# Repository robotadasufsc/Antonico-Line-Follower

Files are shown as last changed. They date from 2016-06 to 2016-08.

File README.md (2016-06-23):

# Antonico-Line-Follower 
A line follower robot designed and built mostly by the new members of the Robota mobile robotics groups.

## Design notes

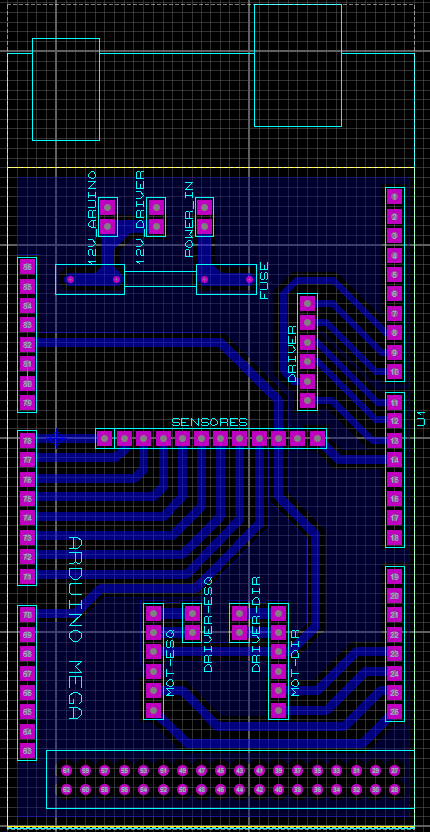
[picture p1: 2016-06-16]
Eletronica/ares.PNG

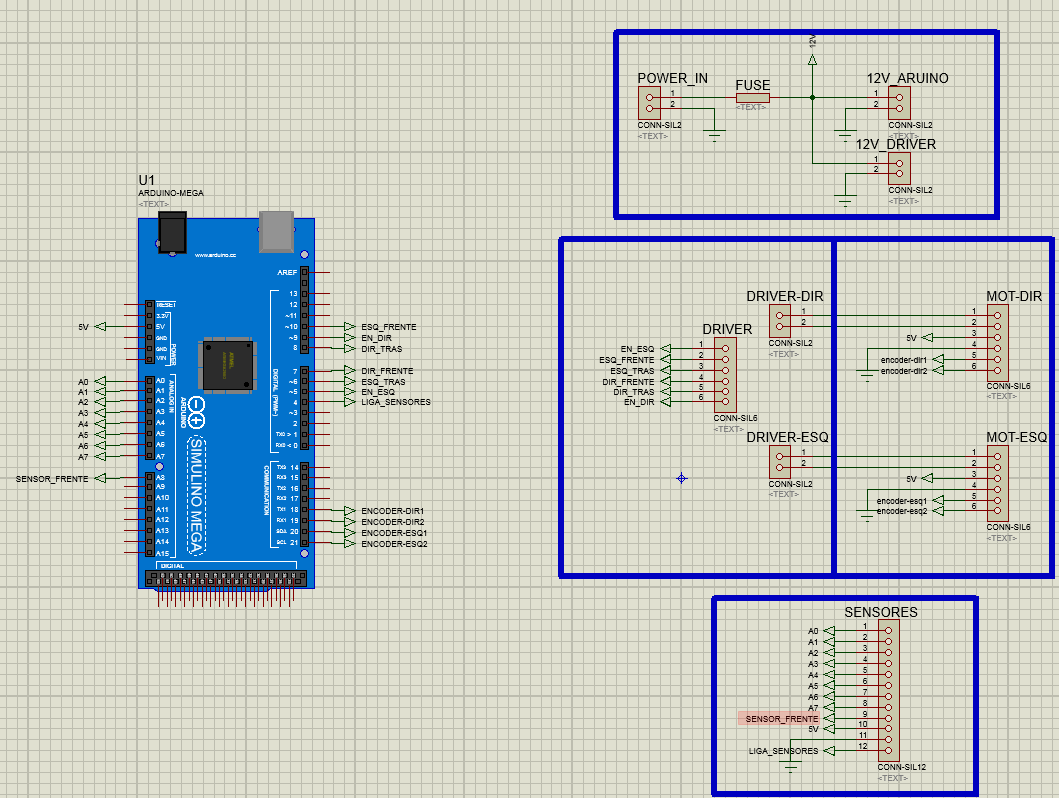
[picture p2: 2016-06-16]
Eletronica/isis.PNG

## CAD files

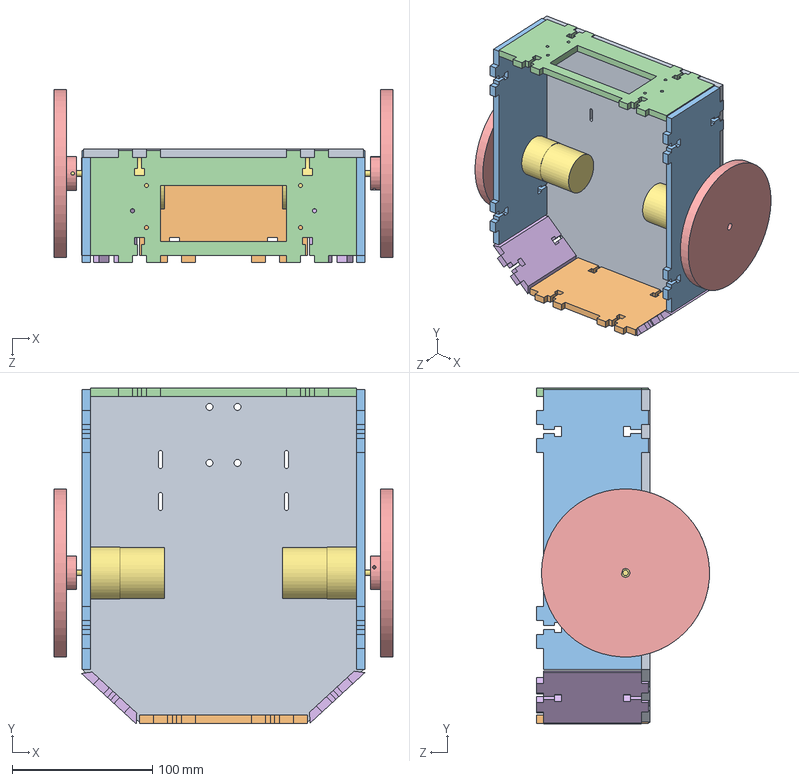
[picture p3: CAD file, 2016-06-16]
Hardware/roboComRoda.SLDASM
242.0 x 239.8 x 123.6 mm
chassi
frente
lateral x 2
traseira
roda x 2
ladoNovo x 2
motor x 2

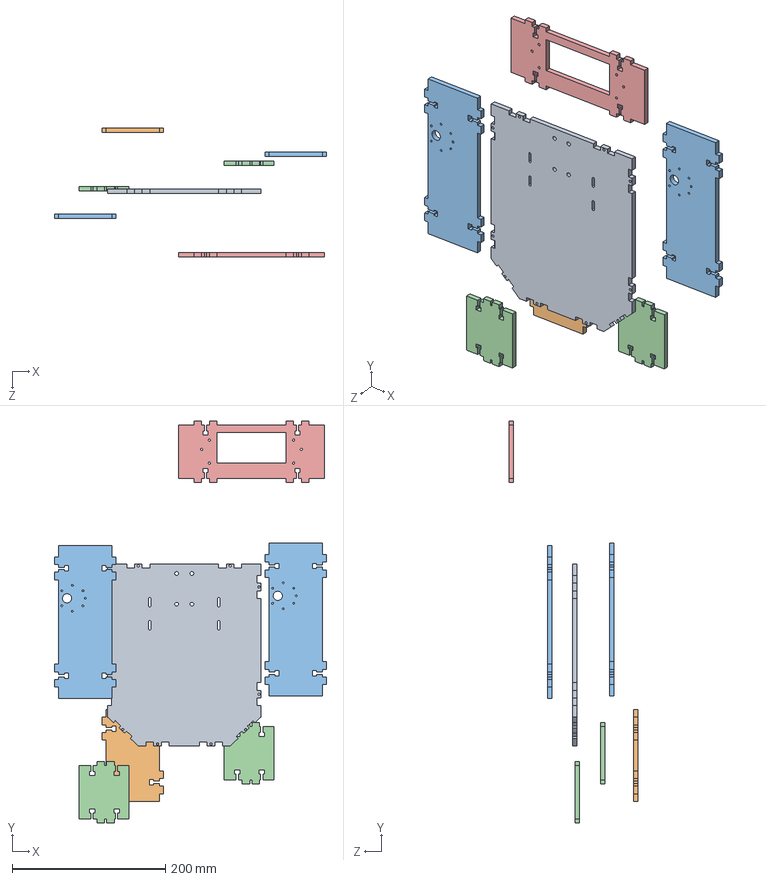
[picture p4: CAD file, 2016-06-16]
Hardware/roboFaltaRoda.SLDASM
355.1 x 524.7 x 168.7 mm
chassi
frente
lateral x 2
latFront x 2
traseira

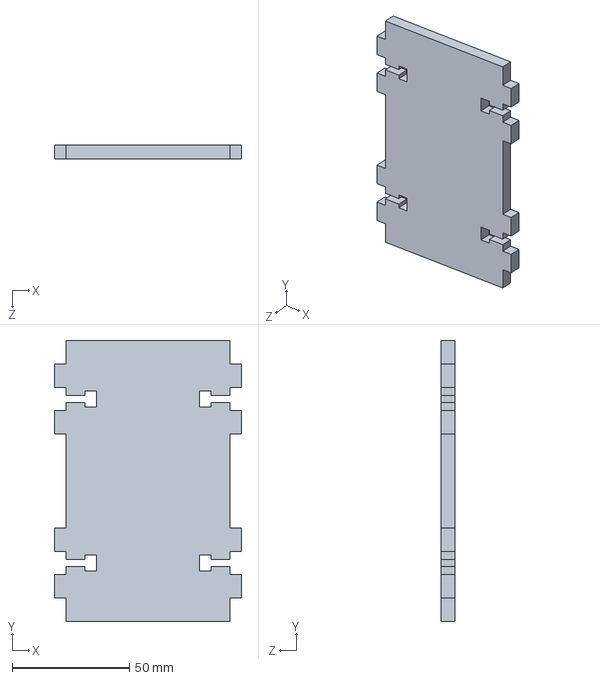
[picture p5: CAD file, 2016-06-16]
Hardware/frente.SLDPRT
80.0 x 120.0 x 6.00 mm

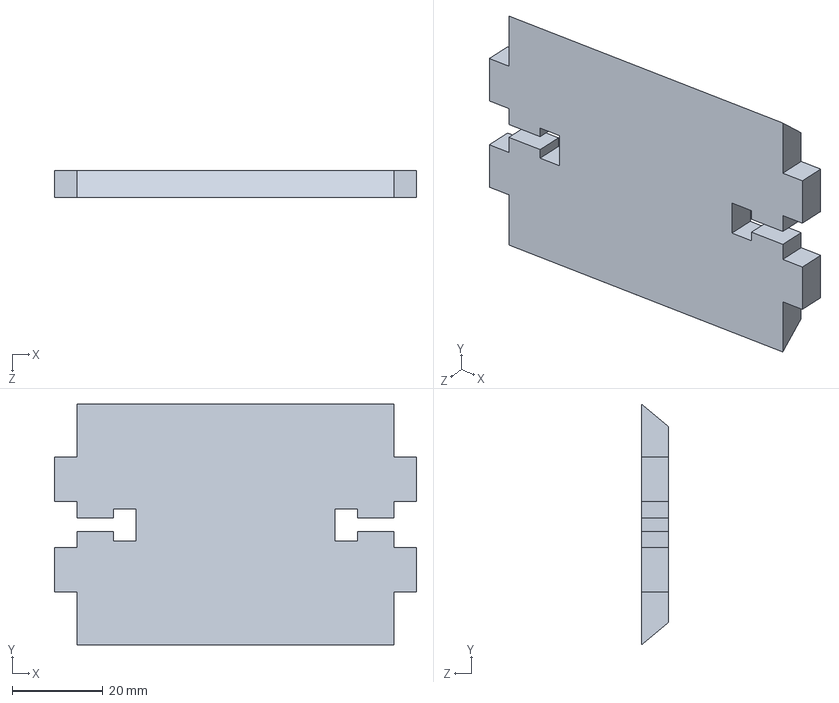
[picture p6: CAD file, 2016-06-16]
Hardware/ladoNovo.SLDPRT
80.0 x 53.2 x 6.00 mm

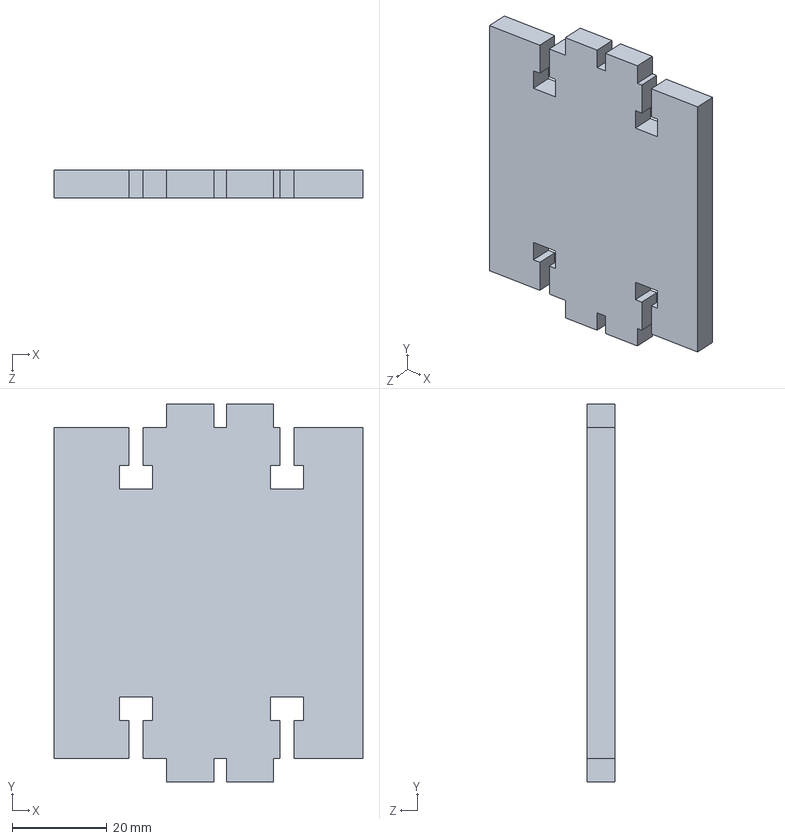
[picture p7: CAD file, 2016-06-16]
Hardware/latFront.SLDPRT
65.3 x 80.0 x 6.00 mm

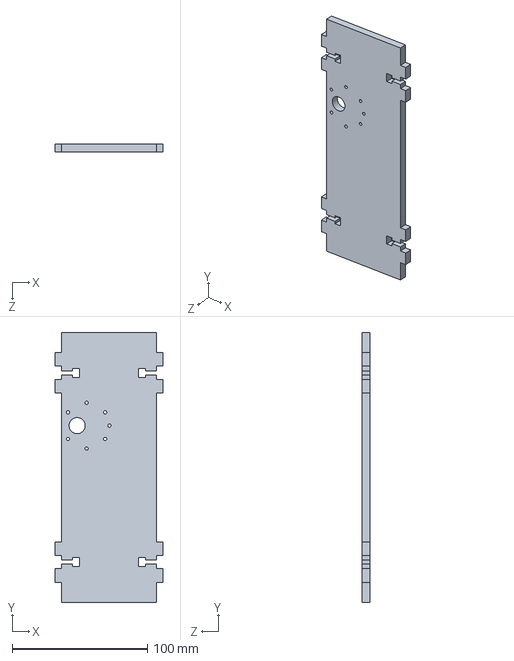
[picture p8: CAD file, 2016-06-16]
Hardware/lateral.SLDPRT
80.0 x 200.0 x 6.00 mm

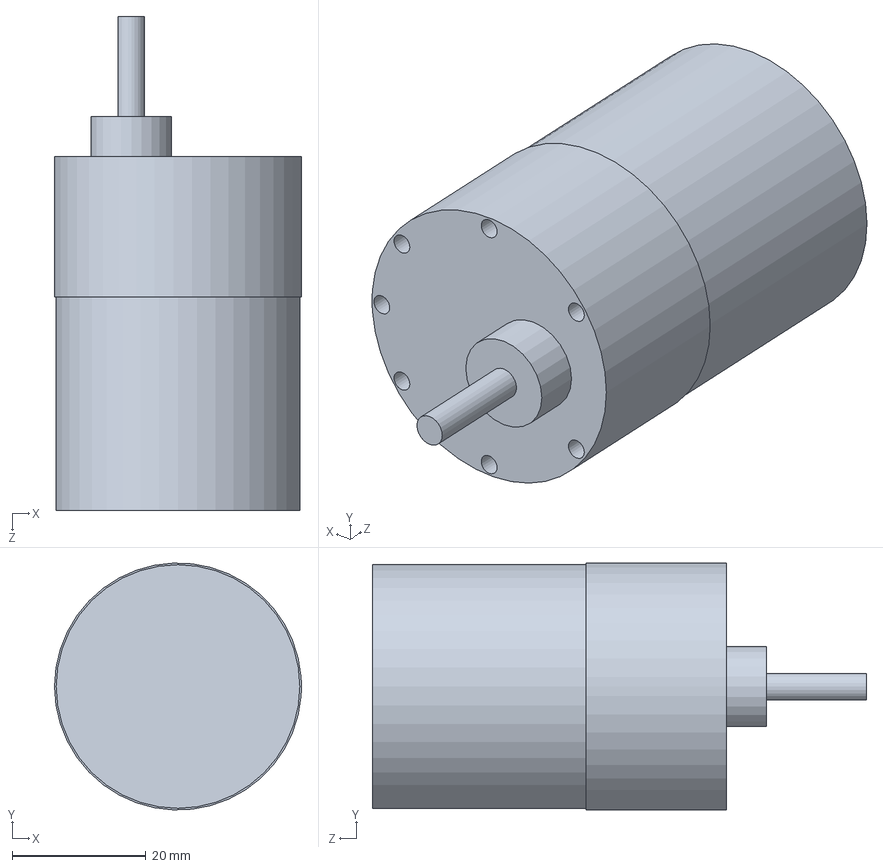
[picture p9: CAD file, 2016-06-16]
Hardware/motor.SLDPRT
37.0 x 37.0 x 74.0 mm

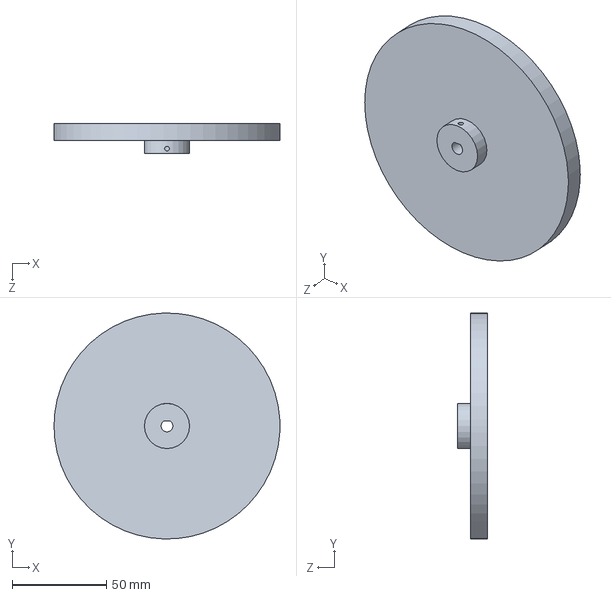
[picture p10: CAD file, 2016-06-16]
Hardware/roda.SLDPRT
120.0 x 119.9 x 16.0 mm

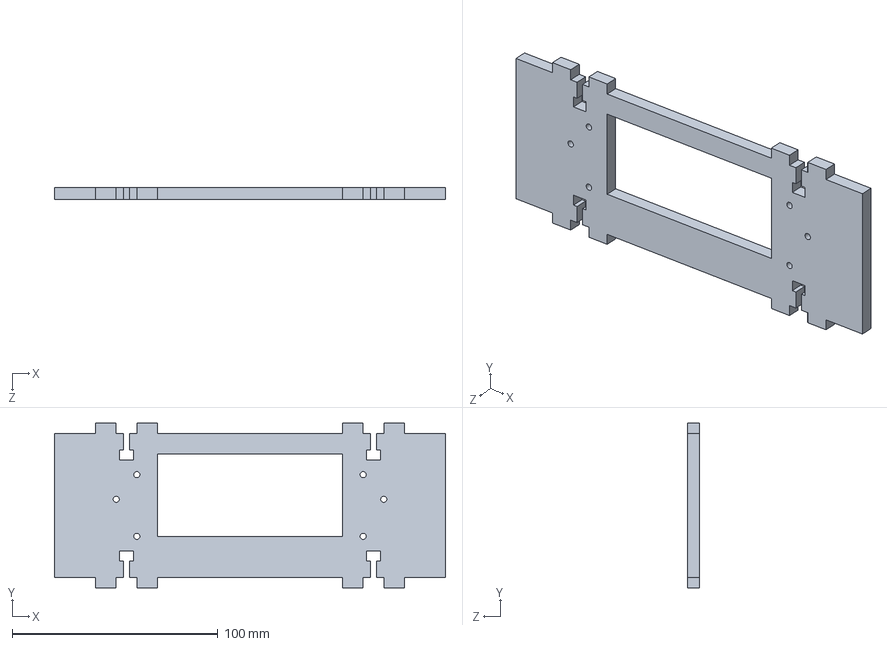
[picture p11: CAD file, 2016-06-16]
Hardware/traseira.SLDPRT
190.0 x 80.0 x 6.00 mm

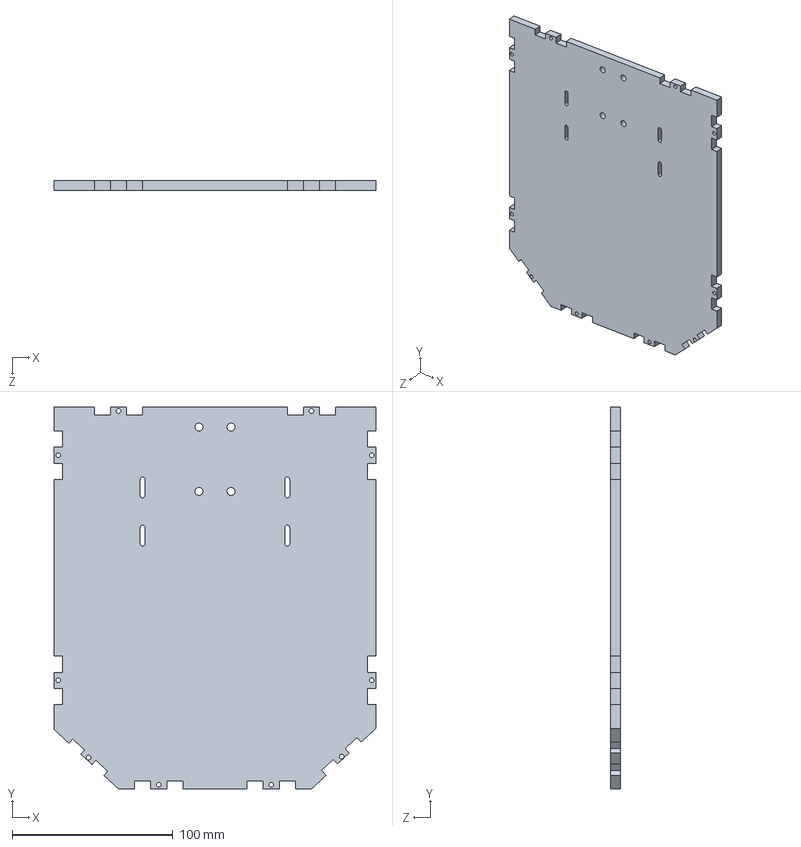
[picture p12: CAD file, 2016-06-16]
Hardware/chassi.SLDPRT
200.0 x 237.6 x 6.00 mm

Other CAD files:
Hardware/frente.SLDDRW
Hardware/ladoNovo.SLDDRW

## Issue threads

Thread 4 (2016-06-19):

Analisar o caso de velocidade == 0 na ponte H

Williangalvani, 2016-06-19:
Existem três opções:
 - Desligar a ponte, deixando o motor livre.
 - Deixar a ponte ligada sem sinal de tensão no motor.
 - Levantar os dois pinos para freiar o motor.

É necessário analizar o efeito de cada uma dessas possibilidade no controle de velocidade implementado.

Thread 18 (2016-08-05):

Create Higher level class to control robot behaviour

Williangalvani, 2016-08-05:
A new class is required, to manage the higher level behaviour,s such as "follow line", calibrate, "avoid obstacles", "sit", "fetch", etc..

patrickelectric, 2016-08-05:
Original thread [here](https://github.com/robotadasufsc/Antonico-Line-Follower/pull/16/commits/8580afde91f4236e2d8429293577c13db63b39e1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).

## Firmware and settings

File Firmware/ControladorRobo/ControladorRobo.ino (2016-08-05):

#include <Arduino.h>
#include <math.h>
#include "hal.h"
#include "irarray.h"
#include "hbridge.h"
#include "control.h"
#include "lib/Encoder/Encoder.h"

#define CONTROLADOR_ROBO_DEBUG

// If CONTROLADOR_ROBO_DEBUG define print debug message
#ifdef CONTROLADOR_ROBO_DEBUG
char debug_buffer[128];
// [Class]: Function:Line: %s
#define debug(fmt, args ...)  do {sprintf(debug_buffer, "[ControladorRobo]: %s:%d: " fmt "\n", __FUNCTION__, __LINE__, ## args); Serial.print(debug_buffer);} while(0)
#else
#define debug(fmt, args ...)
#endif

// constantes
#define freq 50.0
#define actFreq 20

//variaveis para controle de velocidade
float refDir = 0.0;
float refEsq = 0.0;
float basespeed = 0.3;

// posicao angular de cada roda, com provavel perda de resolucao depois de algum tempo.
// será usada para controle de posicao do robô (girar 90º, por exemplo)
float leftAngPos = 0;
float rightAngPos = 0;

// Encoders setup
Encoder left(LEFT_ENCODER_A, LEFT_ENCODER_B);
Encoder right(RIGHT_ENCODER_A,RIGHT_ENCODER_B);

// PID controllers setup
Controller controle_esq = Controller(kc_esq, ti_esq, td_esq, Ts);
Controller controle_dir = Controller(kc_dir, ti_dir, td_dir, Ts);
Controller directionController = Controller(0.1, 0, 0, 1/actFreq);

void peripheralsSetup()
{
    // Seta os pinos de chave como entrada em pull-up
    pinMode(SWITCH1, INPUT_PULLUP);
    pinMode(SWITCH2, INPUT_PULLUP);
    Serial.begin(115200);
}

void setup()
{
    long unsigned int startTime = millis();
    peripheralsSetup();

    HBridge::self(); // makes sure that the H-ridge pins are initialized during setup phase.

    controllersSetup();

    if (digitalRead(SWITCH2))
    {
        IRArray* infrared = &IRArray::self();
        long unsigned int calibrationTimer = millis()+2000; //TODO: Should use encoder data to measure a 360º turn.
        infrared->startCalibration();
        refDir = 1;
        refEsq = -1;
        while (millis()<calibrationTimer)
        {
            infrared->startCalibration();
            infrared->readSensors();
        }
        infrared->endCalibration();
    }
    refDir = 0;
    refEsq = 0;
    delay(100);

    debug("Took %d millis to finish.", millis()-startTime);
}

void loop()
{
    unsigned long nextCycle = millis() + 1000/freq;
    IRArray* infrared = &IRArray::self();
    while (millis() < nextCycle)
    {
    }
    infrared->readSensors();
    float currentLinePos = infrared->estimateLinePosition();
    float u_direction = directionController.update(4.3, currentLinePos);
    refDir = basespeed + u_direction;
    refEsq = basespeed - u_direction;
    basespeed *= 1.001;
}

///////////////////////////////////////////////////////////funcoes//////////////////////////////////////////////////////////////////////////////


// interrupcao para TIMER1, periodo de amostragem para controle de velocidade
ISR(TIMER1_COMPA_vect)
{
    // Calculo das velocidades dos motores

    float rightAngularDelta = ((float)right.read()/ENCODER_RESOLUTION)*M_PI;
    float leftAngularDelta = ((float)left.read()/ENCODER_RESOLUTION)*M_PI;

    float rightAngularSpeed = rightAngularDelta*freq;
    float leftAngularSpeed = leftAngularDelta*freq;

    rightAngPos += rightAngularDelta;
    leftAngPos += leftAngularDelta;

    left.write(0);
    right.write(0);

    float u_esq = controle_esq.update(refEsq, leftAngularSpeed);
    float u_dir = controle_dir.update(refDir, rightAngularSpeed);

    HBridge* bridge = &HBridge::self();
    bridge->setWheelPWM(bridge->LEFT,u_esq);
    bridge->setWheelPWM(bridge->RIGHT,u_dir);

}

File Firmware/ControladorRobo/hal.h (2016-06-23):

#pragma once

#include <Arduino.h>

/*
+-----+
+----[PWR]-------------------| USB |--+
|                            +-----+  |
|           GND/RST2  [ ] [ ]         |
|         MOSI2/SCK2  [ ] [ ]  SCL[ ] |   D0
|            5V/MISO2 [ ] [ ]  SDA[ ] |   D1
|                             AREF[ ] |
|                              GND[ ] |
| [ ]N/C                        13[ ]~|   B7
| [ ]IOREF                      12[ ]~|   B6
| [ ]RST                        11[ ]~|   B5
| [ ]3V3      +----------+      10[ ]~|   B4
| [ ]5v       | ARDUINO  |       9[ ]~|   H6
| [ ]GND      |   MEGA   |       8[ ]~|   H5
| [ ]GND      +----------+            |
| [ ]Vin                         7[ ]~|   H4
|                                6[ ]~|   H3
| [ ]A0                          5[ ]~|   E3
| [ ]A1                          4[ ]~|   G5
| [ ]A2                     INT5/3[ ]~|   E5
| [ ]A3                     INT4/2[ ]~|   E4
| [ ]A4                       TX>1[ ]~|   E1
| [ ]A5                       RX<0[ ]~|   E0
| [ ]A6                               |
| [ ]A7                     TX3/14[ ] |   J1
|                           RX3/15[ ] |   J0
| [ ]A8                     TX2/16[ ] |   H1
| [ ]A9                     RX2/17[ ] |   H0
| [ ]A10               TX1/INT3/18[ ] |   D3
| [ ]A11               RX1/INT2/19[ ] |   D2
| [ ]A12           I2C-SDA/INT1/20[ ] |   D1
| [ ]A13           I2C-SCL/INT0/21[ ] |   D0
| [ ]A14                              |
| [ ]A15                              |   Ports:
|                RST SCK MISO         |    22=A0  23=A1
|         ICSP   [ ] [ ] [ ]          |    24=A2  25=A3
|                [ ] [ ] [ ]          |    26=A4  27=A5
|                GND MOSI 5V          |    28=A6  29=A7
| G                                   |    30=C7  31=C6
| N 5 5 4 4 4 4 4 3 3 3 3 3 2 2 2 2 5 |    32=C5  33=C4
| D 2 0 8 6 4 2 0 8 6 4 2 0 8 6 4 2 V |    34=C3  35=C2
|         ~ ~                         |    36=C1  37=C0
| @ # # # # # # # # # # # # # # # # @ |    38=D7  39=G2
| @ # # # # # # # # # # # # # # # # @ |    40=G1  41=G0
|           ~                         |    42=L7  43=L6
| G 5 5 4 4 4 4 4 3 3 3 3 3 2 2 2 2 5 |    44=L5  45=L4
| N 3 1 9 7 5 3 1 9 7 5 3 1 9 7 5 3 V |    46=L3  47=L2
| D                                   |    48=L1  49=L0    SPI:
|                                     |    50=B3  51=B2     50=MISO 51=MOSI
|     2560                ____________/    52=B1  53=B0     52=SCK  53=SS
\_______________________/
*/

//LED PINS
#define GREENLED 22
#define YELLOWLED 23

//SWITCH PINS
#define SWITCH1 52
#define SWITCH2 53

//LED Control
#define greenLedOff()      digitalWrite(GREENLED, HIGH)
#define greenLedOn()       digitalWrite(GREENLED, LOW)
#define greenLedToggle()   digitalWrite(GREENLED, !digitalRead(GREENLED))
#define yellowLedOff()    digitalWrite(YELLOWLED, HIGH)
#define yellowLedOn()     digitalWrite(YELLOWLED, LOW)
#define yellowLedToggle() digitalWrite(YELLOWLED, !digitalRead(YELLOWLED))

//// H-Bridge Pins
#define RIGHT_WHEEL_FORWARD_PIN 8
#define RIGHT_WHEEL_BACKWARD_PIN 7
#define RIGHT_WHEEL_SPEED_PIN 9

#define LEFT_WHEEL_FORWARD_PIN 6
#define LEFT_WHEEL_BACKWARD_PIN 10
#define LEFT_WHEEL_SPEED_PIN 5

// Encoder
#define RIGHT_ENCODER_A 21
#define RIGHT_ENCODER_B 20  // B is out of phase by 90 degrees

#define LEFT_ENCODER_A 18
#define LEFT_ENCODER_B 19 // B is out of phase by 90 degrees

#define ENCODER_RESOLUTION 3200

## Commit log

2016-06-16 Added hardware files
    [MINICURSO.SLDPRT, chassi.SLDPRT, frente.SLDDRW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]
2016-06-16 Re-implemented PID controllers
    [MINICURSO.SLDPRT, chassi.SLDPRT, frente.SLDDRW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]
2016-06-16 fixed wrong pin adressing on wheels
    [ControladorRobo.ino]
2016-06-19 Delete MINICURSO.SLDPRT
    Essa peça era a escada do Minicurso - não faz parte do robô.
    [MINICURSO.SLDPRT]
2016-06-19 implemented new calibration routine, enabled reading wheel positions
2016-06-19 Transforma Calib em uma classe, Fix #1
    Tira alguns _trailing spaces_ no ControladorRobo.ino
    [ControladorRobo.ino]
2016-06-19 Cria classe HBridge, Fix #2
    [ControladorRobo.ino, hbridge.cpp]
2016-06-19 Move led and wheels definitions to hal.h, change them to english
2016-06-19 Fixes: - HBridge: - Change LEFT_WHEEL to LEFT - Change RIGHT_WHEEL to RIGHT
    - ControladorRobo.ino:
    - Added TODO on calibration routine
    [ControladorRobo.ino, hbridge.cpp]
2016-06-20 controle: Add pragma once and Arduino.h include
2016-06-20 encoder: Add pragma once and Arduino.h include
2016-06-20 irarray: New functions and enable pin added
    - turnOn,turnOff: functions to enable or disable IR array.
    - m_enablePin: new variable to store the enable pin.
2016-06-20 ControladorRobo: Move calibrationTimer to setup
2016-06-23 Fix controllers saturation levels Previously they were unable to give negative output to move the wheels backwards.
2016-06-23 Add Encoder submodule
2016-06-23 Use new encoder lib. - Add Encoder lib - Modify code to use Encoder lib - Re-implement wheel speed and displacement calculation
2016-06-23 Change calibration routine. So it turns the robot around its central axis if SWITCH2 is on during startup
2016-06-23 Lower default PID gains They were too high, making the wheels unstable.
2016-06-23 Fix H bridge It was trying to generate a negative PWM signal, effectively applying (255 - vel) to the wheels when receiving a negative speed. Also commented it's initialization in setup()
    [ControladorRobo.ino, hbridge.cpp]
2016-08-05 instantiate invididual speed controllers for each wheel
2016-08-05 Change Hbridge so it now receives a [1,-1] speed range, changed controllers gains accordingly
    Fix #11
    [ControladorRobo.ino, hbridge.cpp]
2016-08-05 IRArray improvemnts - Made it start turned on by default; - New sensor reading function; - Called readSensors during calibration phase, so the calibration actually happens
2016-08-05 change callibration timer to turn only one time during calibration
2016-08-05 HBridge: handle case where speed==0
2016-08-05 Make IRArray remember line position when it's out of sensors range
2016-08-05 fix calibration not being loaded, and defaults being set on the wrong place
    [irarray.cpp]
2016-08-05 Make calibration run continuously
2016-08-05 Enable IRArray::sensor to return NORMAL, MIN, or MAX values for each sensor
2016-08-05 Change IRArray::sensorLow and IRArray::sensorMAX to uint8_t, for clarity
